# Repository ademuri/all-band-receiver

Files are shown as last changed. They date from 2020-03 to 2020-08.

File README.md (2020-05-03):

# All-band receiver

This is a PCB for the audio amplifier IC version of the [Techlib Amazing All-Band Receiver](http://www.techlib.com/electronics/allband.htm). It is a device that makes the normally-invisible world of RF audible.

"This is not an officially supported Google product"

## Versions

The latest and greatest version is in [low-voltage](low-voltage). This version is powered by 4xAAA, and is relatively simple. This is the one you want to build.

[all-through-hole](all-through-hole) and [audio-rf](audio-rf) contain the previous (overengineered) version, which was powered by a single 18650 lithium-ion battery. It used a boost converter followed by a linear regulator to step the battery voltage up to 9v. This is overkill, and also caused noise issues.

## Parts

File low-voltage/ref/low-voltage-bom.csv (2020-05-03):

Ref | Package | Qty | Value | Digikey part number | Manufacturer part number
BT1 | BatteryHolder_Keystone_2481_4xAAA | 1 | Battery | 36-2481-ND | 2481
C10,C9,C1 | CP_Radial_D5.0mm_P2.00mm | 3 | 10uF | 732-8856-1-ND | 860020672010
C11 | C_Disc_D3.8mm_W2.6mm_P2.50mm | 1 | 47000pF | BC5153-ND | K473K15X7RF53L2
C13,C12 | CP_Radial_D6.3mm_P2.50mm | 2 | 220uF | 732-8634-1-ND | 860010473011
C3 | C_Disc_D5.0mm_W2.5mm_P5.00mm | 1 | 100pF | BC5223CT-ND | K101J10C0GF5UH5
C5 | CP_Radial_D5.0mm_P2.00mm | 1 | 1uF | 732-8851-1-ND | 860020672005
C6,C4 | C_Disc_D5.0mm_W2.5mm_P5.00mm | 2 | 1000pF | BC2659CT-ND | K102K10X7RF5UH5
C8,C7,C2 | C_Disc_D5.1mm_W3.2mm_P5.00mm | 3 | 0.1uF | 478-2472-ND | SR215C104KAA
D1 | D_DO-35_SOD27_P7.62mm_Horizontal | 1 | BAT41 | 497-2493-1-ND | BAT41
D2 | LED_D5.0mm_Horizontal_O1.27mm_Z9.0mm | 1 | LED | C5SMF-RJF-CT0W0BB1-ND | C5SMF-RJF-CT0W0BB1
J1 | MOLEX_0731713150 | 1 | Conn_Coaxial | 731713150 | WM20430-ND
LS1 | CLS0231MP-1_SPEAKER | 1 | Speaker | 102-1543-ND | CLS0231MP-1
Q1 | TO-92_Inline_Wide | 1 | 2N4401 | 2N4401TFCT-ND | 2N4401TF
R3 | R_Axial_DIN0207_L6.3mm_D2.5mm_P10.16mm_Horizontal | 1 | 100 | CF14JT100RCT-ND | CF14JT100R
R4 | R_Axial_DIN0207_L6.3mm_D2.5mm_P10.16mm_Horizontal | 1 | 22k | CF14JT22K0CT-ND | CF14JT22K0
R5,R2 | R_Axial_DIN0207_L6.3mm_D2.5mm_P10.16mm_Horizontal | 2 | 1M | RNF14FTD1M00CT-ND | RNF14FTD1M00
R6 | R_Axial_DIN0207_L6.3mm_D2.5mm_P10.16mm_Horizontal | 1 | 1k | CF14JT1K00CT-ND | CF14JT1K00
R7 | R_Axial_DIN0207_L6.3mm_D2.5mm_P10.16mm_Horizontal | 1 | 1.3k | 1.30KXBK-ND | MFR-25FBF52-1K3
R8 | R_Axial_DIN0207_L6.3mm_D2.5mm_P10.16mm_Horizontal | 1 | 10 | CF18JT10R0CT-ND | CF18JT10R0
R9,R1 | R_Axial_DIN0207_L6.3mm_D2.5mm_P10.16mm_Horizontal | 2 | 10k | CF14JT10K0CT-ND | CF14JT10K0
RV1 | Potentiometer_Bourns_PTV09A-2_Single_Horizontal | 1 | 10k_pot | PTV09A-2020F-A103-ND | PTV09A-2020F-A103
SW2,SW1 | ‎EG1206‎_SLIDE_SWITCH | 2 | SW_SPST | EG1916-ND | EG1206
U1 | DIP-8_W7.62mm | 1 | LM386 | 296-44414-5-ND | LM386N-1/NOPB

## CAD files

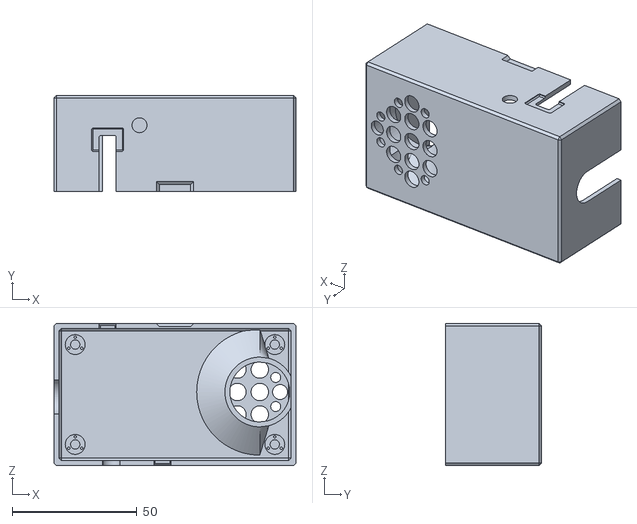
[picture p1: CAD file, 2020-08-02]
low-voltage/top.stl
97.0 x 38.6 x 57.0

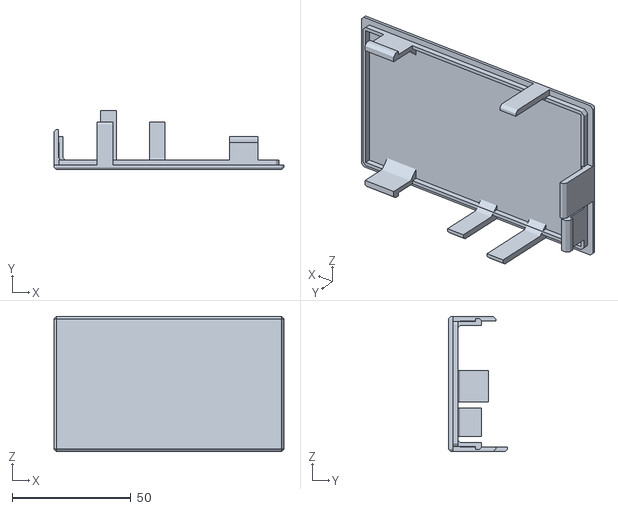
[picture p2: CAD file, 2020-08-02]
low-voltage/bottom.stl
97.0 x 25.0 x 57.0

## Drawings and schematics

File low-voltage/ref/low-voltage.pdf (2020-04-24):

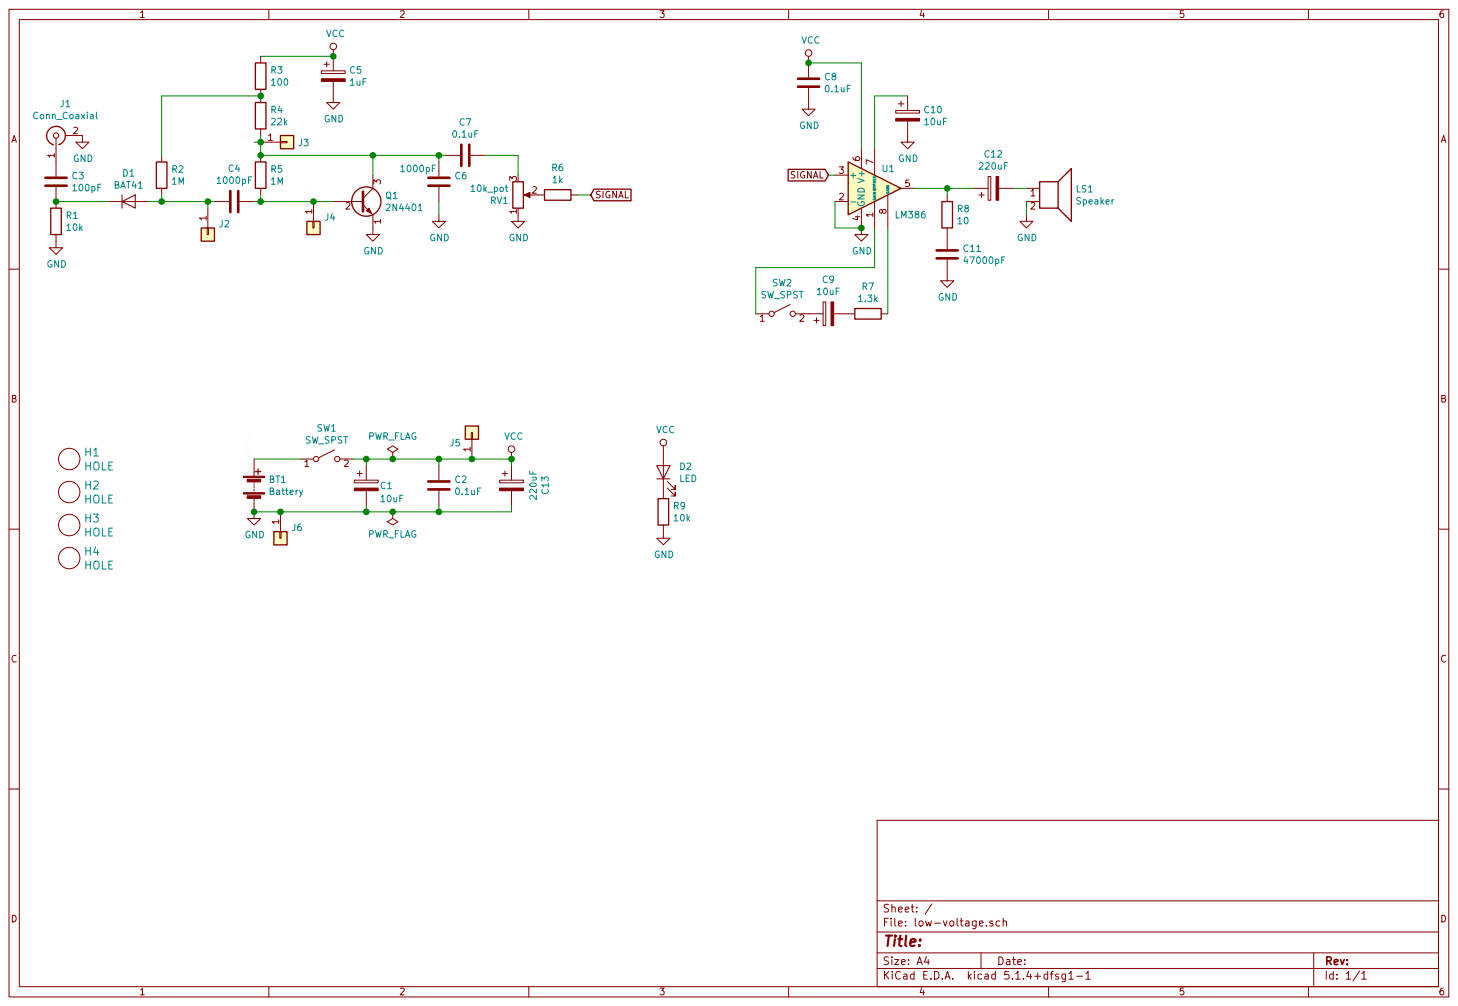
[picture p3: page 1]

File: low-voltage.sch Sheet: /
Id: 1/1 Title:

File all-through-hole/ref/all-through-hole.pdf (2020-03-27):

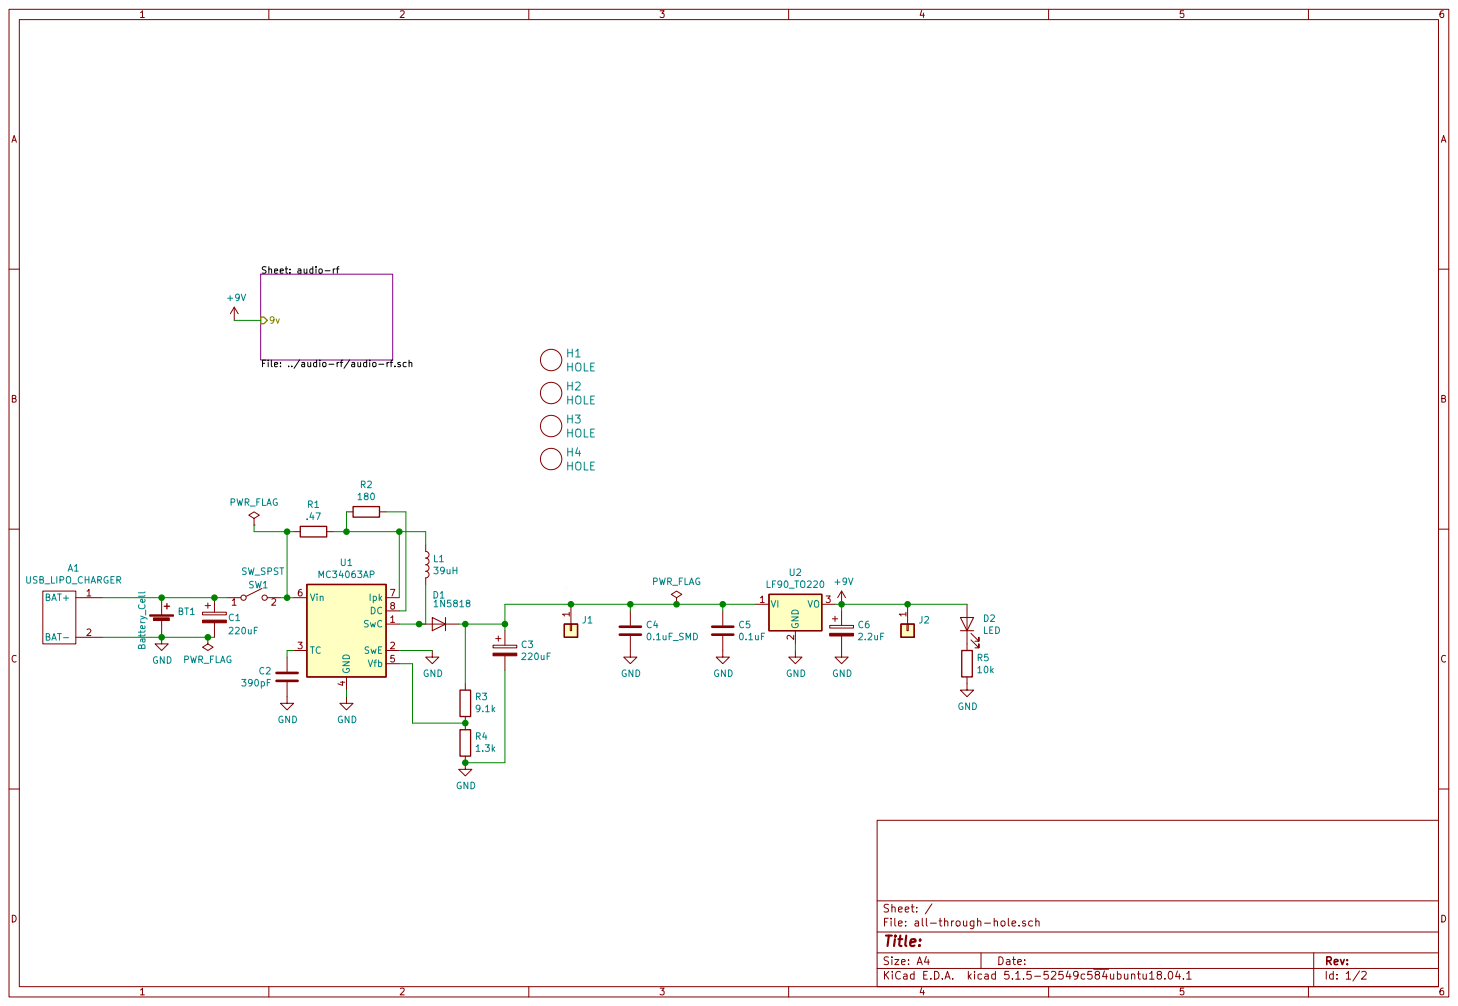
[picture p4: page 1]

Sheet: audio-rf File: ../audio-rf/audio-rf.sch

PWR_FLAG H1 HOLE H2 HOLE H3 HOLE H4 HOLE

File: all-through-hole.sch Sheet: /
Id: 1/2 Title:

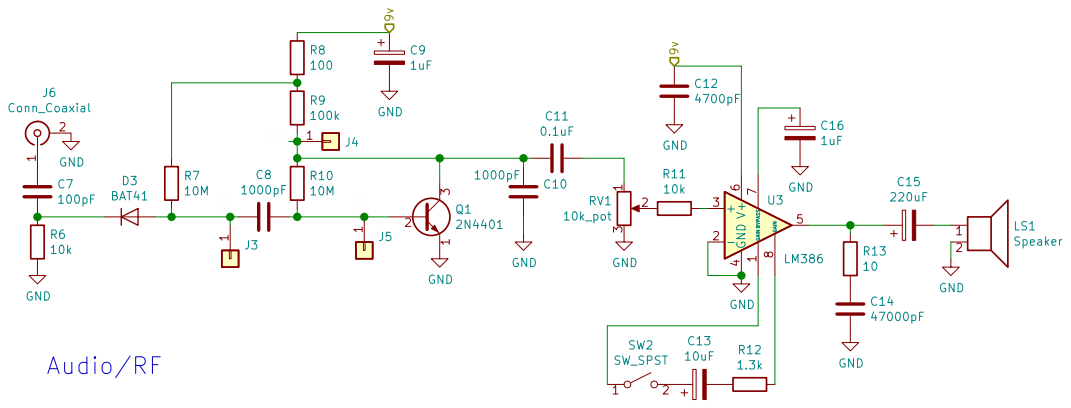
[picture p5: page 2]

Id: 2/2 Title: File: audio-rf.sch Sheet: /audio-rf/

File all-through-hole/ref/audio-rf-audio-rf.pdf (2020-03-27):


Id: 2/2 Title: File: audio-rf.sch Sheet: /audio-rf/

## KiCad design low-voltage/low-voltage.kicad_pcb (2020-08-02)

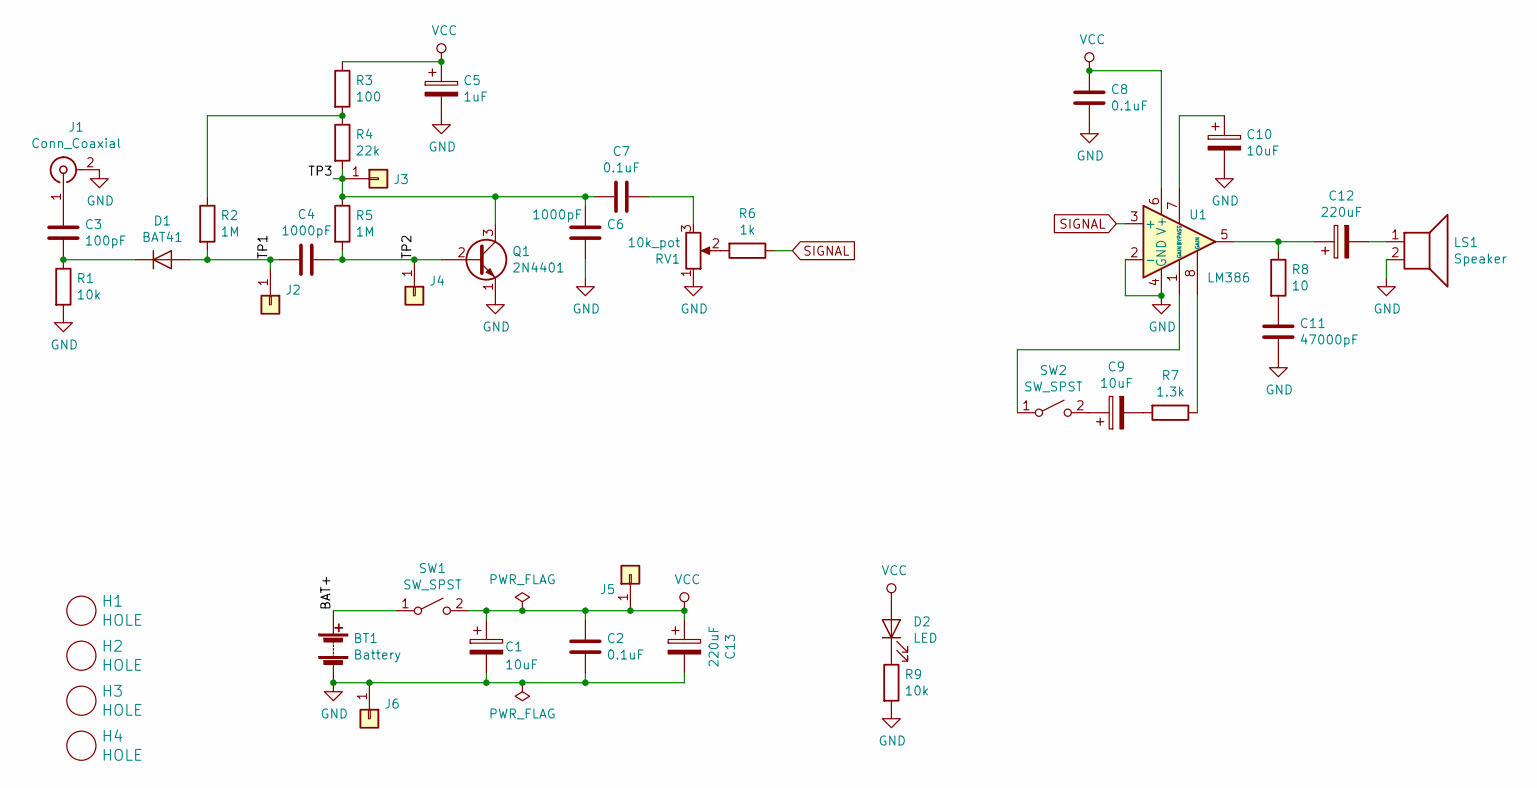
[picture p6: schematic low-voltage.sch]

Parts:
BT1: Battery; BatteryHolder_Keystone_2481_4xAAA
C1, C9, C10: 10uF; CP_Radial_D5.0mm_P2.00mm
C2, C7, C8: 0.1uF; C_Disc_D5.1mm_W3.2mm_P5.00mm
C3: 100pF; C_Disc_D5.0mm_W2.5mm_P5.00mm
C4, C6: 1000pF; C_Disc_D5.0mm_W2.5mm_P5.00mm
C5: 1uF; CP_Radial_D5.0mm_P2.00mm
C11: 47000pF; C_Disc_D3.8mm_W2.6mm_P2.50mm
C12, C13: 220uF; CP_Radial_D6.3mm_P2.50mm
D1: BAT41; D_DO-35_SOD27_P7.62mm_Horizontal
D2: LED; LED_D5.0mm_Horizontal_O1.27mm_Z9.0mm
H1, H2, H3, H4: HOLE; HOLE_5MM_#8
J1: Conn_Coaxial; MOLEX_0731713150
J2, J3, J4: Conn_01x01; PinHeader_1x01_P2.54mm_Vertical
J5, J6: Conn_01x01; ALLIGATOR_CLIP_SLOT
LS1: Speaker; CLS0231MP-1_SPEAKER
Q1: 2N4401; TO-92_Inline_Wide
R1, R9: 10k; R_Axial_DIN0207_L6.3mm_D2.5mm_P10.16mm_Horizontal
R2, R5: 1M; R_Axial_DIN0207_L6.3mm_D2.5mm_P10.16mm_Horizontal
R3: 100; R_Axial_DIN0207_L6.3mm_D2.5mm_P10.16mm_Horizontal
R4: 22k; R_Axial_DIN0207_L6.3mm_D2.5mm_P10.16mm_Horizontal
R6: 1k; R_Axial_DIN0207_L6.3mm_D2.5mm_P10.16mm_Horizontal
R7: 1.3k; R_Axial_DIN0207_L6.3mm_D2.5mm_P10.16mm_Horizontal
R8: 10; R_Axial_DIN0207_L6.3mm_D2.5mm_P10.16mm_Horizontal
RV1: 10k_pot; Potentiometer_Bourns_PTV09A-2_Single_Horizontal
SW1, SW2: SW_SPST; ‎EG1206‎_SLIDE_SWITCH
U1: LM386; DIP-8_W7.62mm

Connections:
/BAT+: BT1.1 (+), SW1.1 (A)
/TP1: C4.2, D1.2 (A), J2.1, R2.2
/TP2: C4.1, J4.1, Q1.2 (B), R5.2
/TP3: C6.1, C7.2, J3.1, Q1.3 (C), R4.2, R5.1
GND: BT1.2 (-), C1.2, C2.2, C5.2, C6.2, C8.2, C10.2, C11.2, C13.2, J1.2 (Ext), J6.1, LS1.2, Q1.1 (E), R1.2, R9.2, RV1.1, U1.2 (-), U1.4 (GND)
unnamed: C3.1, J1.1 (In)
unnamed: C3.2, D1.1 (K), R1.1
unnamed: C7.1, RV1.3
unnamed: C9.1, SW2.2 (B)
unnamed: C9.2, R7.2
unnamed: C10.1, U1.7 (BYPASS)
unnamed: C11.1, R8.2
unnamed: C12.1, R8.1, U1.5
unnamed: C12.2, LS1.1
unnamed: D2.1 (K), R9.1
unnamed: R2.1, R3.2, R4.1
unnamed: R6.2, RV1.2
unnamed: R7.1, U1.8 (GAIN)
unnamed: SW2.1 (A), U1.1 (GAIN)
SIGNAL: R6.1, U1.3 (+)
VCC: C1.1, C2.1, C5.1, C8.1, C13.1, D2.2 (A), J5.1, R3.1, SW1.2 (B), U1.6 (V+)

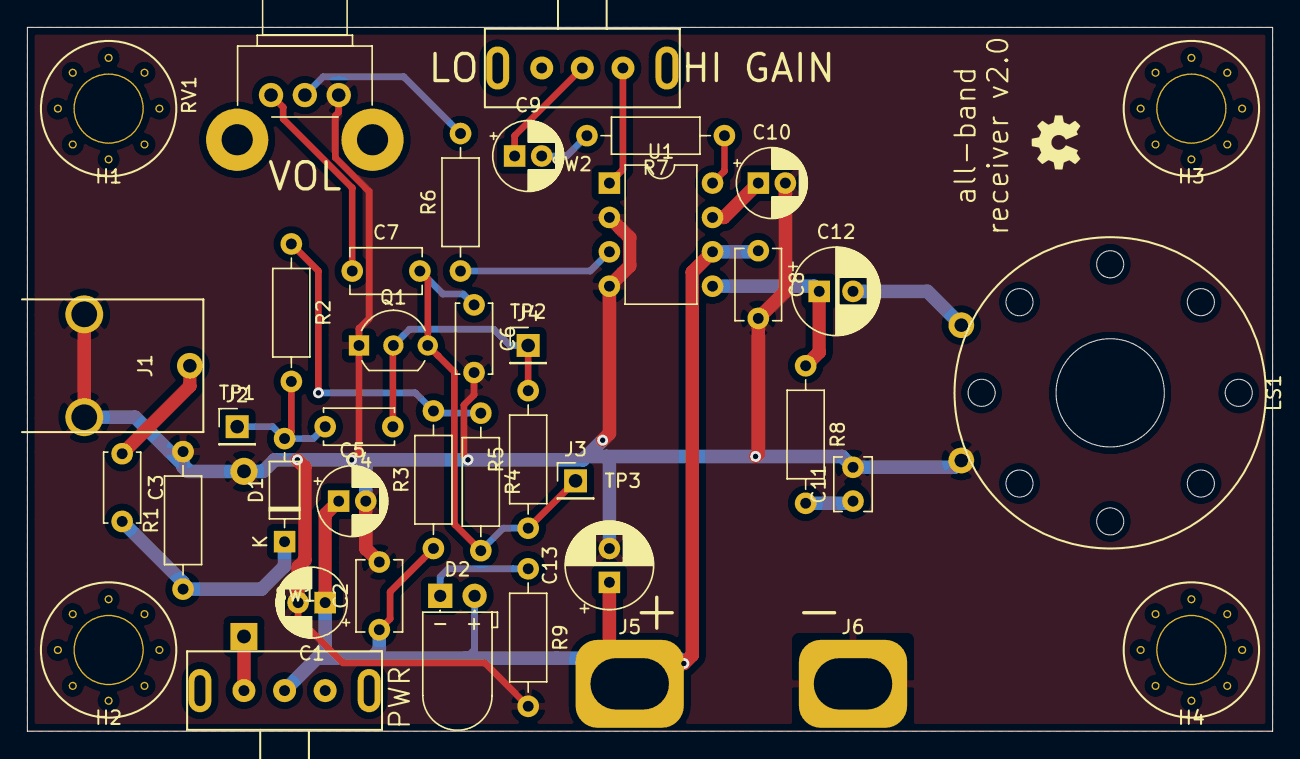
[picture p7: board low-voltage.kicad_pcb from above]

Board: 2 copper layers, 92.0 x 52.0 mm, 41 parts (1 on the bottom side), 21 nets.

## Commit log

2020-03-25 Add rf/audio, start adding power supply
    [all-band-receiver.kicad_pcb, all-band-receiver.sch]
2020-03-27 First pass at all-through-hole schematic
    [all-band-receiver.sch, all-through-hole.kicad_pcb, all-through-hole.sch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]
2020-03-27 Associate footprints for all-through-hole
    [all-through-hole.sch, audio-rf.sch]
2020-03-27 First pass at layout
    [all-through-hole.sch, audio-rf.sch]
2020-03-27 Hardware v1.0
    [all-through-hole-B_Cu.gbr, all-through-hole-B_Mask.gbr, all-through-hole-B_Paste.gbr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]
2020-04-03 Add interactive bom for all-through-hole v1.0
2020-04-04 Remove unused partial-semd
    [partial-smd.kicad_pcb, partial-smd.sch]
2020-04-14 Add a schematic for a low-voltage version.
    PCB and BOM are not complete.
    [low-voltage.kicad_pcb, low-voltage.sch]
2020-04-19 Change low voltage to use lm386 instead of njm2113
    [low-voltage.sch]
2020-04-21 Place components for low voltage
    [low-voltage.kicad_pcb, low-voltage.sch]
2020-04-24 Final design for low voltage (v2.0)
    [low-voltage-B_Cu.gbr, low-voltage-B_Mask.gbr, low-voltage-B_Paste.gbr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]
2020-05-03 Add BOM and update README
    [low-voltage-bom.csv]
2020-08-01 Add 3d model for pot
    [low-voltage.kicad_pcb]
2020-08-02 Add 3d models for BNC connector and slide switch
    [low-voltage.kicad_pcb]
2020-08-02 Add 3d model for low voltage board
    [low-voltage.kicad_pcb]
2020-08-02 Add case STL files
    [bottom.stl, top.stl]
2020-08-02 Add finger catch and pcb mount bumps to case top
    [top.stl]
